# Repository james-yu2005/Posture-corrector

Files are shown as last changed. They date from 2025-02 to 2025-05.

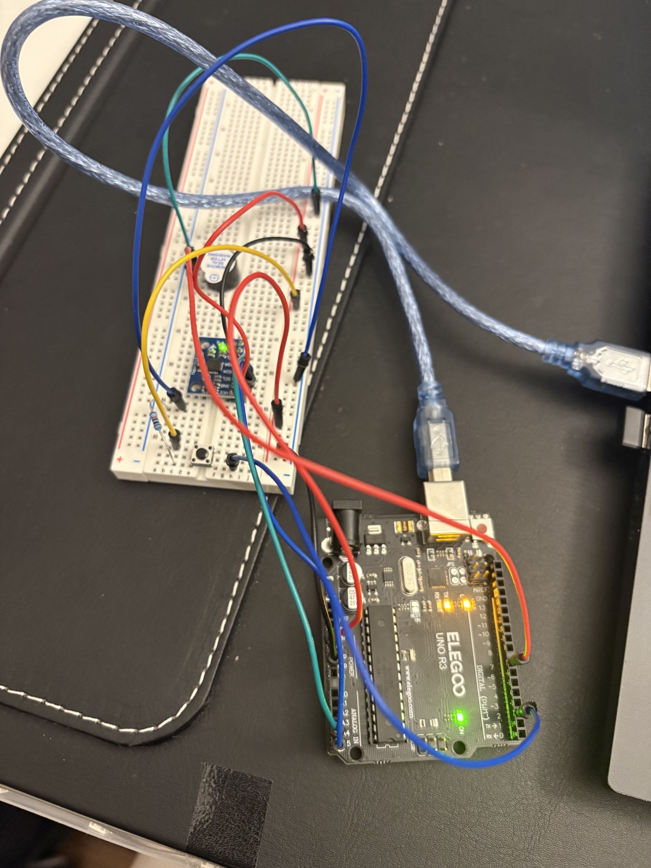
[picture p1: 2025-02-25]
arduino/posture_corrector.jpg

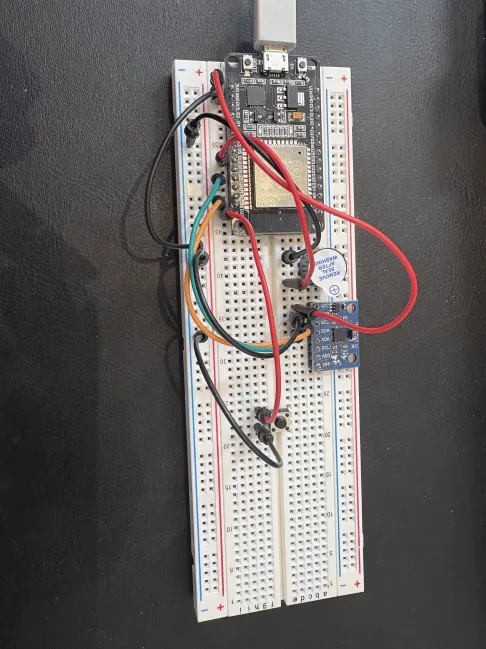
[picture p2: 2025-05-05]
esp32/posture_corrector.webp

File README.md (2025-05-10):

# 🎯 Posture Corrector Device

## 🎥 Demo Videos

Explore both iterations in action:

- ▶️ **ESP32 + OpenCV-based Posture Corrector (2nd Iteration)**  
- ▶️ **Arduino-based Posture Corrector (1st Iteration)**

📁 [Watch the Demo Videos on Google Drive](https://drive.google.com/drive/folders/1XhhxoisGqGbtTAvJfZo68UkWgdPwPm_9?usp=drive_link)

---

## 🧠 Overview

A wearable device that uses real-time sensor feedback and computer vision to promote proper posture.

This device monitors upper back and neck posture using an **MPU-6050** sensor and a custom **OpenCV** model. Upon detecting poor posture, it emits an audible alert via a buzzer to notify the user.

---

## 🔧 First Iteration (Prototype)

- Built using an **Arduino Uno R3**, **MPU-6050**, and a **breadboard**.
- Detected angular deviations in back posture and triggered a buzzer during slouching.

---

## 🚀 Second Iteration (Refined)

- Upgraded to an **ESP32** microcontroller for wireless communication and improved performance.
- Integrated an **OpenCV + MediaPipe** model to track **neck posture** using webcam input and calculate head tilt angles.
- Real-time communication between OpenCV and ESP32 triggers the buzzer when poor neck posture is detected.
- Designed a **3D-printed wearable enclosure** using **SolidWorks** to house the electronics.
- 📂 Computer vision source code: [OpenCV Posture Model](https://github.com/james-yu2005/posture_corrector_code)

---

## 🛠️ Hardware Improvements

- Designed a **custom PCB** to replace the breadboard, enhancing compactness, reliability, and ease of assembly.
- A new **SolidWorks 3D enclosure** is in development for the updated hardware version.

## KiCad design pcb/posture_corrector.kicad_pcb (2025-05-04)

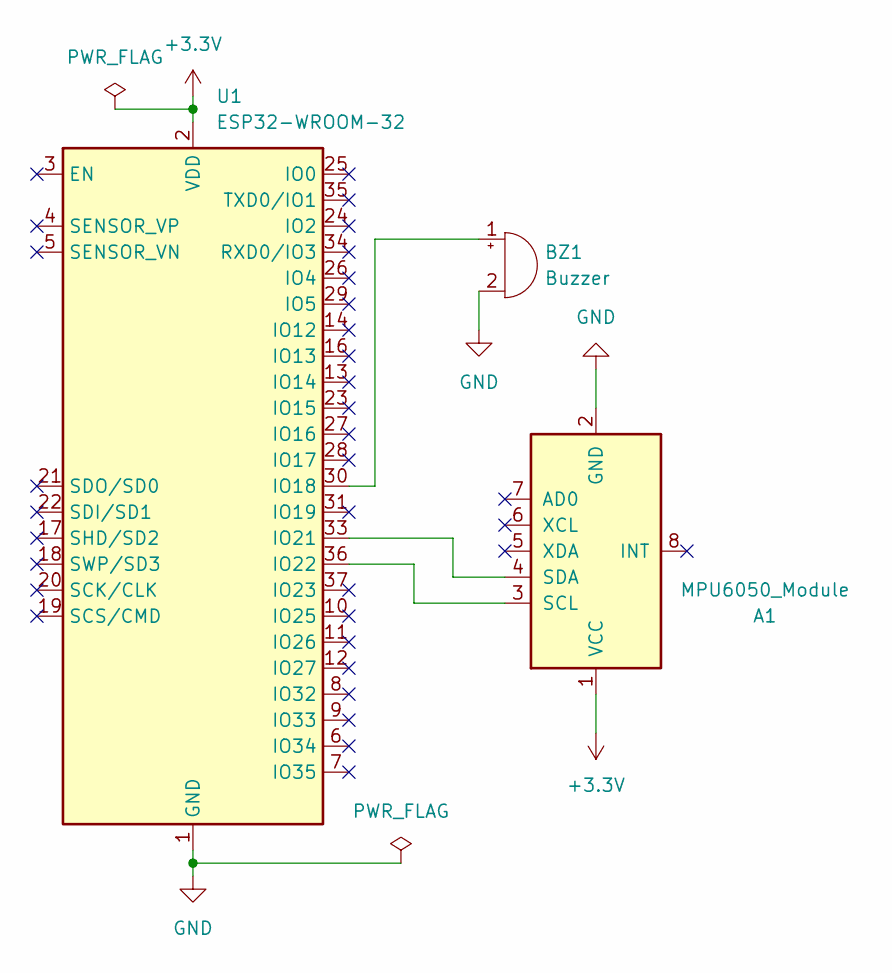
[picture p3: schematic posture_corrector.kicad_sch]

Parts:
A1: MPU6050_Module
BZ1: Buzzer; Buzzer_12x9.5RM7.6
U1: ESP32-WROOM-32

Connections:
+3.3V: A1.1 (VCC), U1.2 (VDD)
GND: A1.2 (GND), BZ1.2 (-), U1.1 (GND), U1.15 (GND), U1.38 (GND), U1.39 (GND)
unnamed: A1.3 (SCL), U1.36 (IO22)
unnamed: A1.4 (SDA), U1.33 (IO21)
unnamed: BZ1.1 (+), U1.30 (IO18)

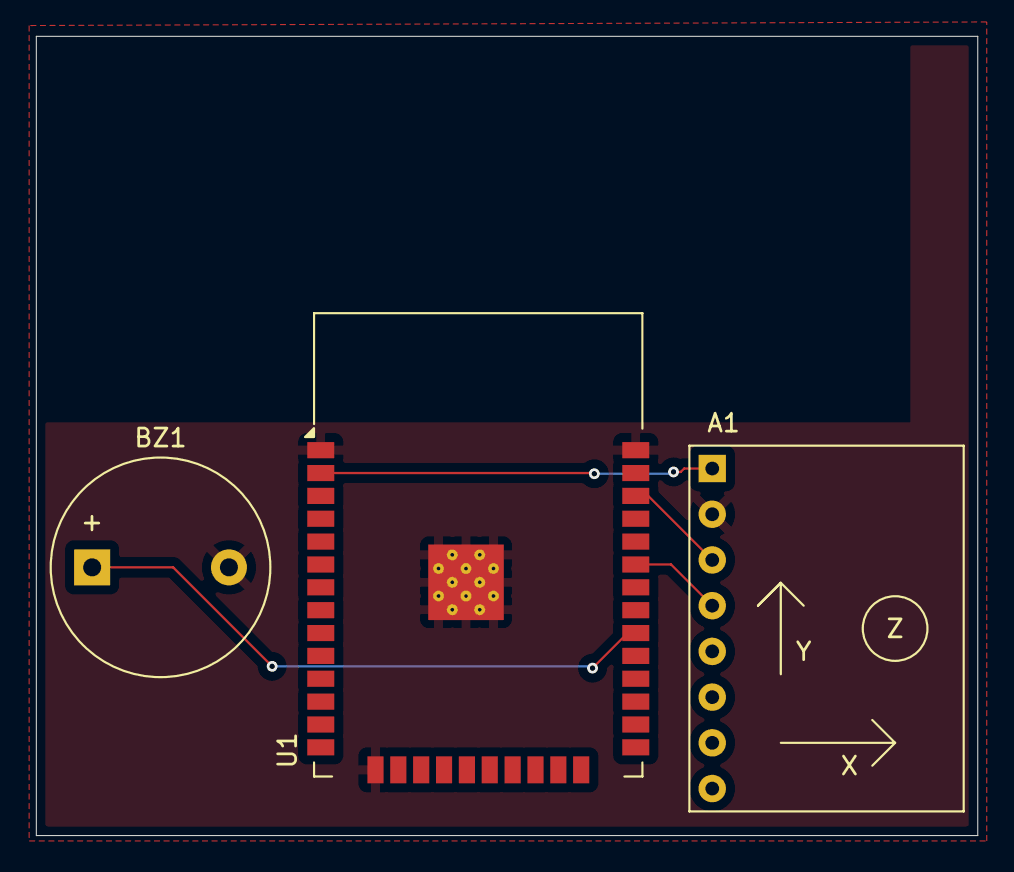
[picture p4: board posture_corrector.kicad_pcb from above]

Board: 4 copper layers, 52.3 x 44.4 mm, 3 parts (0 on the bottom side), 5 nets.

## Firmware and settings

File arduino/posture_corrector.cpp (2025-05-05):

#include <Wire.h>

const int MPU = 0x68;  // MPU6050 I2C address
const int buttonPin = 2; 
float AccX, AccY, AccZ;  // Accelerometer readings
float GyroX, GyroY, GyroZ;  // Gyroscope readings

int buttonState = 0; 

float kalmanAngleX, kalmanAngleY;  // Filtered angles
float AngleX, AngleY;
float absAngleX, absAngleY;
float biasX = 0, biasY = 0;  // Gyro bias
float P[2][2] = {{1, 0}, {0, 1}};  // Error covariance matrix
float dt = 0.01;  

float initial_x = 0, initial_y = 0; 
bool initial_read = false;  // Flag to check if initial angles are set

const int buzzerPin = 7; 

void setup() {
  pinMode(buttonPin, INPUT);

  Serial.begin(19200);
  Wire.begin();

  // Initialize MPU6050
  Wire.beginTransmission(MPU);
  Wire.write(0x6B);
  Wire.write(0x00);
  Wire.endTransmission(true);

  delay(1000);  
  read_initial_data();  

  pinMode(buzzerPin, OUTPUT);  
}

void read_MPU6050_data() {
  Wire.beginTransmission(MPU);
  Wire.write(0x3B);
  Wire.endTransmission(false);
  Wire.requestFrom(MPU, 6, true);

  AccX = (Wire.read() << 8 | Wire.read()) / 4096.0;
  AccY = (Wire.read() << 8 | Wire.read()) / 4096.0;
  AccZ = (Wire.read() << 8 | Wire.read()) / 4096.0;

  Wire.beginTransmission(MPU);
  Wire.write(0x43);
  Wire.endTransmission(false);
  Wire.requestFrom(MPU, 6, true);

  GyroX = (Wire.read() << 8 | Wire.read()) / 32.8;
  GyroY = (Wire.read() << 8 | Wire.read()) / 32.8;
  GyroZ = (Wire.read() << 8 | Wire.read()) / 32.8;
}

void read_initial_data() {
  read_MPU6050_data();
  
  float accelAngleX = atan(AccY / sqrt(AccX * AccX + AccZ * AccZ)) * 180 / PI;
  float accelAngleY = atan(-AccX / sqrt(AccY * AccY + AccZ * AccZ)) * 180 / PI;

  initial_x = accelAngleX;
  initial_y = accelAngleY;
  initial_read = true;
}

void loop() {
  read_MPU6050_data();

  float accelAngleX = atan(AccY / sqrt(AccX * AccX + AccZ * AccZ)) * 180 / PI;
  float accelAngleY = atan(-AccX / sqrt(AccY * AccY + AccZ * AccZ)) * 180 / PI;

  float rateX = GyroX - biasX;
  float rateY = GyroY - biasY;

  kalmanAngleX += rateX * dt;
  kalmanAngleY += rateY * dt;

  P[0][0] += dt;
  P[1][1] += dt;

  float K[2] = {P[0][0] / (P[0][0] + 0.1), P[1][1] / (P[1][1] + 0.1)};

  kalmanAngleX += K[0] * (accelAngleX - kalmanAngleX);
  kalmanAngleY += K[1] * (accelAngleY - kalmanAngleY);

  P[0][0] -= K[0] * P[0][0];
  P[1][1] -= K[1] * P[1][1];

  // Calculate absolute change from initial angles
  AngleX = kalmanAngleX - initial_x;
  AngleY = kalmanAngleY - initial_y;
  absAngleX = abs(AngleX);
  absAngleY = abs(AngleY);

  Serial.print("Roll Change: ");
  Serial.print(absAngleX);
  Serial.print(" | Pitch Change: ");
  Serial.println(absAngleY);

  // If the absolute angle is above 20 degrees, activate the buzzer
  if (absAngleX > 20 || absAngleY > 20) {
    digitalWrite(buzzerPin, HIGH); 
  } else {
    digitalWrite(buzzerPin, LOW);  
  }

  buttonState = digitalRead(buttonPin);
  // check if the pushbutton is pressed. If it is, then reset all angles, which turns of buzzer
  if (buttonState == HIGH) {
    read_initial_data();
    kalmanAngleX = 0;
    kalmanAngleY = 0;
    Serial.println("Angles reset!");
  }
  delay(10);
}

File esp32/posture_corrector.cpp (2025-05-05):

#include <Wire.h>
#include <math.h>
#include <WiFi.h>
#include <WebServer.h>

const char* ssid = "wifi";       // Replace with your WiFi SSID
const char* password = "pswd";   // Replace with your WiFi password

WebServer server(80);

// MPU6050 I2C address
#define MPU6050_ADDR 0x68

// Registers
#define PWR_MGMT_1 0x6B
#define ACCEL_XOUT_H 0x3B

#define BUZZER_PIN 18 

// Variables to store sensor data
int16_t ax, ay, az;

float roll = 0.0;
float pitch = 0.0;
float initial_roll = 0.0;
float initial_pitch = 0.0;

// Threshold for change in angle
float angle_threshold = 20.0;

// Flag for manual buzzer control
bool manual_buzzer_override = false;
bool manual_buzzer_state = false;

void setup() {
  Serial.begin(115200);
  
  WiFi.begin(ssid, password);
  Serial.println("Connecting to WiFi...");
  
  while (WiFi.status() != WL_CONNECTED) {
    delay(500);
    Serial.print(".");
  }
  
  Serial.println("");
  Serial.println("WiFi connected");
  Serial.print("IP address: ");
  Serial.println(WiFi.localIP());
  
  // Initialize web server routes
  server.on("/buzzer-on", handleBuzzerOn);
  server.on("/buzzer-off", handleBuzzerOff);
  
  server.begin();
  Serial.println("HTTP server started");
  
  Wire.begin();
  
  // Wake up the MPU6050
  Wire.beginTransmission(MPU6050_ADDR);
  Wire.write(PWR_MGMT_1); 
  Wire.write(0); 
  Wire.endTransmission(true);
  
  pinMode(BUZZER_PIN, OUTPUT);
  
  delay(100);

  // Read the initial accelerometer data to calculate the initial angles
  Wire.beginTransmission(MPU6050_ADDR);
  Wire.write(ACCEL_XOUT_H);
  Wire.endTransmission(false);
  Wire.requestFrom(MPU6050_ADDR, 6, true); // Request 6 bytes of data
  
  ax = (Wire.read() << 8) | Wire.read();
  ay = (Wire.read() << 8) | Wire.read();
  az = (Wire.read() << 8) | Wire.read();
  
  // Convert accelerometer data to 'g' (sensor is set to ±2g)
  float ax_g = ax / 16384.0;
  float ay_g = ay / 16384.0;
  float az_g = az / 16384.0;

  // Calculate the initial roll and pitch angles (starting angles)
  initial_roll = atan2(ay_g, az_g) * 180.0 / M_PI;
  initial_pitch = atan2(-ax_g, sqrt(ay_g * ay_g + az_g * az_g)) * 180.0 / M_PI;

  Serial.print("Initial Roll: ");
  Serial.print(initial_roll);
  Serial.print("\tInitial Pitch: ");
  Serial.println(initial_pitch);
}

void loop() {
  // Handle client requests
  server.handleClient();
  
  // If manual buzzer control is active, use that state
  if (manual_buzzer_override) {
    digitalWrite(BUZZER_PIN, manual_buzzer_state ? HIGH : LOW);
  } 
  else {
    // Read accelerometer data
    Wire.beginTransmission(MPU6050_ADDR);
    Wire.write(ACCEL_XOUT_H);
    Wire.endTransmission(false);
    Wire.requestFrom(MPU6050_ADDR, 6, true); // Request 6 bytes of data
    
    ax = (Wire.read() << 8) | Wire.read();
    ay = (Wire.read() << 8) | Wire.read();
    az = (Wire.read() << 8) | Wire.read();
  
    // Convert accelerometer data to 'g' (sensor is set to ±2g)
    float ax_g = ax / 16384.0;
    float ay_g = ay / 16384.0;
    float az_g = az / 16384.0;
  
    // Calculate the current roll and pitch angles
    roll = atan2(ay_g, az_g) * 180.0 / M_PI;
    pitch = atan2(-ax_g, sqrt(ay_g * ay_g + az_g * az_g)) * 180.0 / M_PI;
    
    Serial.print("Roll: ");
    Serial.print(roll);
    Serial.print("\tPitch: ");
    Serial.println(pitch);
  
    // Determine if back posture alert should be active based on tilt
    bool bad_posture = (fabs(roll - initial_roll) > angle_threshold || 
                         fabs(pitch - initial_pitch) > angle_threshold);
                         
    digitalWrite(BUZZER_PIN, bad_posture ? HIGH : LOW);
  }
  
  // Small delay to prevent CPU hogging
  delay(100);
}

void handleBuzzerOn() {
  manual_buzzer_override = true;
  manual_buzzer_state = true;
  server.send(200, "text/plain", "Buzzer turned ON");
  Serial.println("Manual buzzer ON");
}

void handleBuzzerOff() {
  manual_buzzer_override = true;
  manual_buzzer_state = false;
  server.send(200, "text/plain", "Buzzer turned OFF");
  Serial.println("Manual buzzer OFF");
}

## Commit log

2025-03-11 Create esp32_posture
2025-05-03 Create esp32_posture_monitor
2025-05-03 Update esp32_posture_monitor
2025-05-03 Create pcb-design
2025-05-04 Update and rename esp32.kicad_pcb to posture_corrector.kicad_pcb
    [posture_corrector.kicad_pcb]
2025-05-04 Update and rename esp32.kicad_sch to posture_corrector..kicad_sch
    [posture_corrector..kicad_sch]
2025-05-04 Update and rename posture_corrector..kicad_sch to posture_corrector.kicad_sch
    [posture_corrector.kicad_sch]
